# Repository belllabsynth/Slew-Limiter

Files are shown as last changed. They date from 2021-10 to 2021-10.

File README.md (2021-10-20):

# Slew Limiter

This is a simple eurorack slew limiter, with a very low parts count that is quick and easy to build. There are no extra frills, just a pot for slew amount, a toggle switch to select between slewing up, down, or both, one input, and one output. 

I drew the schematic from a stripboard layout done by user Mcshafty on the Look Mum No Computer discourse forums ([link here](https://lookmumnocomputer.discourse.group/t/slew-generator-stripboard-confirmed-working/1865)), which is based off of schematics from [Dintree](https://dintree.com) and [YuSynth](https://yusynth.com).

*General Notes:* 

* Current revision (v1.2) of board is untested as of yet, though past versions have worked as expected. I will update and remove this text when I get my new boards in.
* The included Gerber files have been generated for JLCPCB and have not been tested with manufacturers. I have included silkscreen text on the back of both the main board and the panel to avoid JLC printing the batch number on the front. Remove the text saying "JLCJLCJLCJLC" if printing elsewhere and you care to have that removed.
* JLCPCB does not detect the pcb size for the front panel. You can enter it as 128x20mm.
* Depending on your rack, the v1.0 and v1.1 boards may have been too long and not clear your rails. There are no traces below the output jacks ground leg and you can carefully cut a little bit off the board below there if needed. This have been fixed in v1.2.

*Changes In v1.2:*

* Change C4 and C5 from polarized 10uf capacitors to one (now C3) bipolar 4.7uf capacitor
* Resize main board PCB to 100mm height to fix potential clearance issue and reduce manufacturing cost
* Re-design board to make the build a little bit easier
* Change power header footprint to a shrouded header, taken from the [Winterbloom GitHub](https://github.com/wntrblm)
* Increase silkscreen text size and edgecut line thickness to avoid possible issues at certain PCB houses
* Add "JLCJLCJLCJLC" text to main board PCB and front panel so JLC doesn't put their batch number on the front
* Misc schematic changes to improve readability

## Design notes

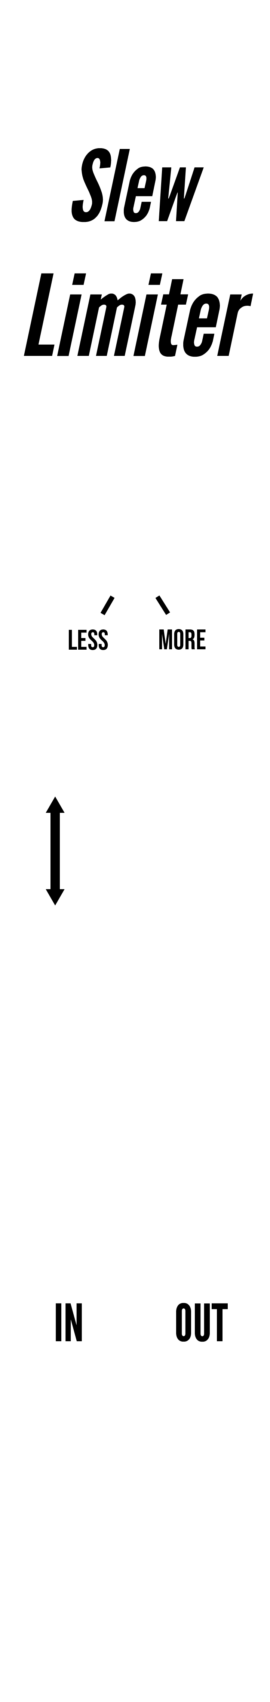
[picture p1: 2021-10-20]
04 Graphics Files/Slew Limiter Panel Graphics.png

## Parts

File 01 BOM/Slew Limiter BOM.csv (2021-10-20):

Reference(s) | Value | Qty | Description
C1, C2 | 10uf | 2 | Polarized radial capacitor
C3 | 4.7uf | 1 | Bipolar radial capacitor
C4, C5 | 100nf | 2 | Ceramic disc capacitor
D1, D2 | 1N5817 | 2 | Diode
D3, D4 | 1N4148 | 2 | Diode
J1 | Input | 1 | Thonkiconn
J2 | Output | 1 | Thonkiconn
JP1 | PWR | 1 | Power header
R1, R2 | 100r | 2 | 1/4w resistor
R3, R4 | 100k | 2 | 1/4w resistor
R5 | 1k | 1 | 1/4w resistor
RV1 | 250k lin | 1 | Alpha 9mm vertical pot
SW1 | ON-OFF-ON | 1 | SPDT switch – Tayda 1M series
U1 | TL072 | 1 | OpAmp

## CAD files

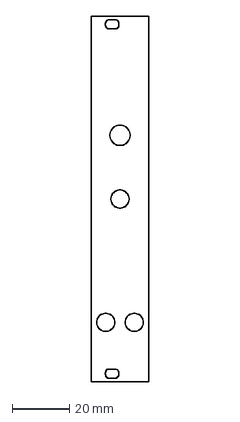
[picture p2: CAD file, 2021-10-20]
04 Graphics Files/Slew Limiter Panel Edge Cuts.dxf
20.0 x 128.0 mm

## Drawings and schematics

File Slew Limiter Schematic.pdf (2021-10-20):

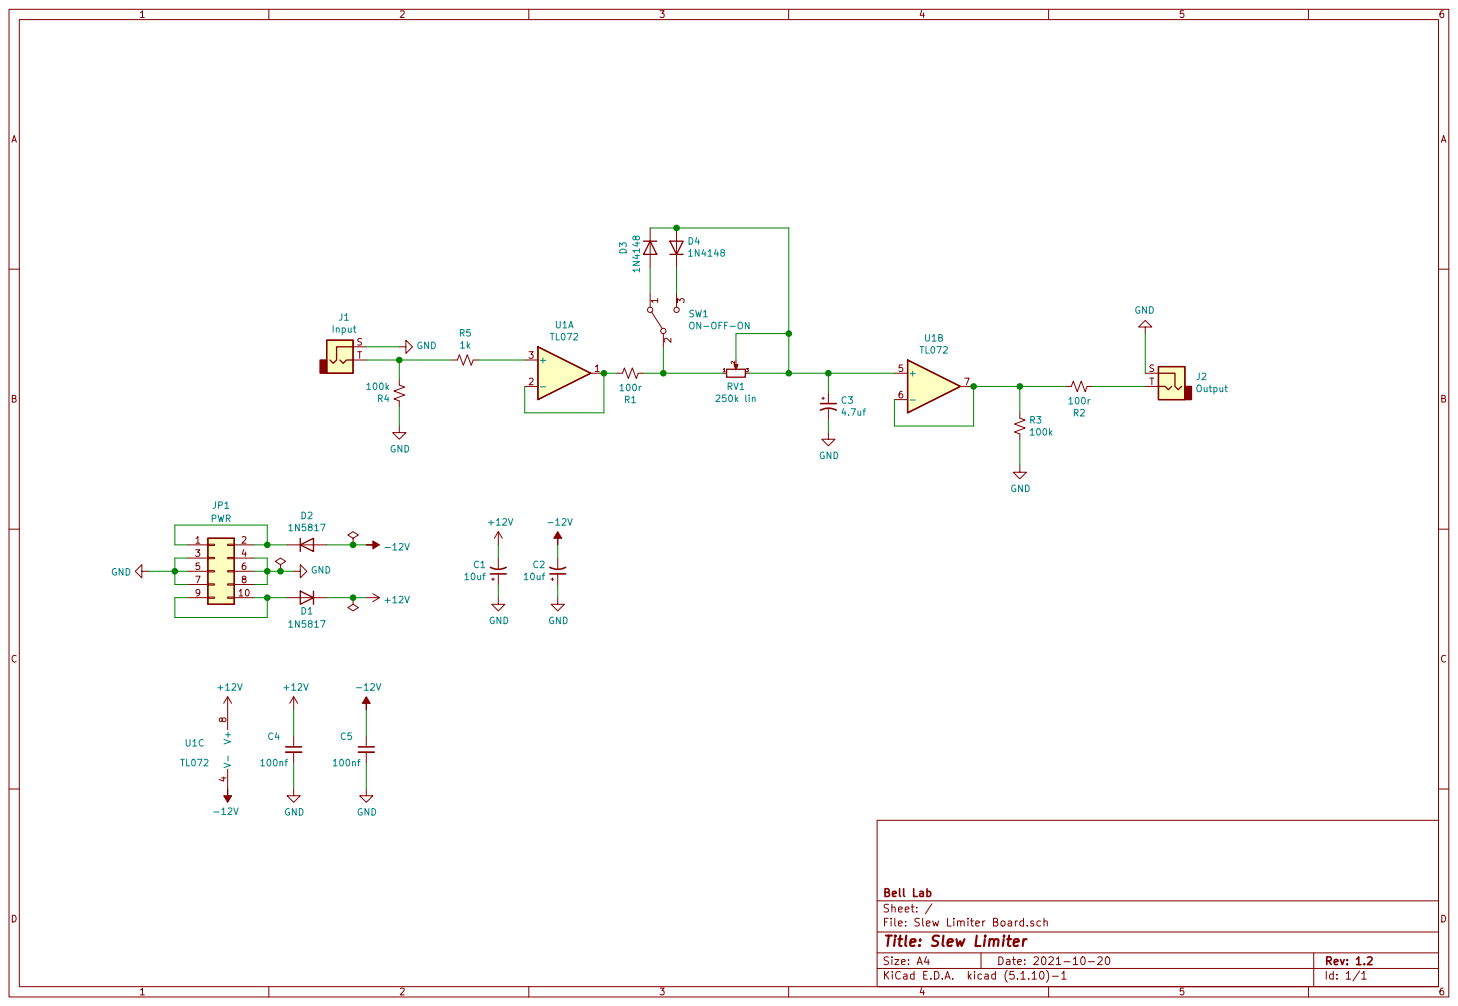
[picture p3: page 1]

3 SW1 ON-OFF-ON D3 1N4148 GND

Id: 1/1 Title: Slew Limiter File: Slew Limiter Board.sch Sheet: / Bell Lab D2

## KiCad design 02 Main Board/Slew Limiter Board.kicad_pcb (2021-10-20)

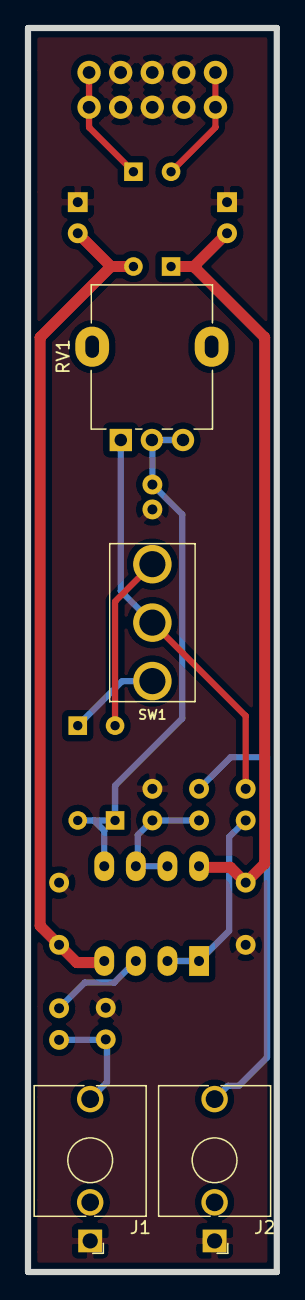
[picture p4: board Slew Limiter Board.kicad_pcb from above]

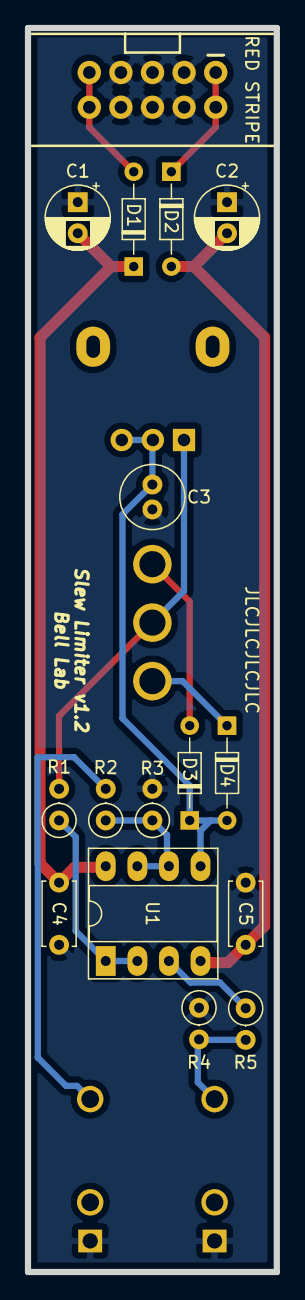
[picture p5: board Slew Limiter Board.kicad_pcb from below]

Board: 2 copper layers, 20.0 x 100.0 mm, 20 parts (16 on the bottom side), 14 nets.

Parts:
C1, C2: 10uf; CP_Radial_D5.0mm_P2.50mm
C3: 4.7uf; C_Radial_D5.0mm_H11.0mm_P2.00mm
C4, C5: 100nf; C_Disc_D5.0mm_W2.5mm_P5.00mm
D1, D2: 1N5817; D_DO-34_SOD68_P7.62mm_Horizontal
D3, D4: 1N4148; D_DO-34_SOD68_P7.62mm_Horizontal
J1: Input; Jack_3.5mm_QingPu_WQP-PJ398SM_Vertical_CircularHoles
J2: Output; Jack_3.5mm_QingPu_WQP-PJ398SM_Vertical_CircularHoles
JP1: PWR; Eurorack_Power
R1, R2: 100r; R_Axial_DIN0207_L6.3mm_D2.5mm_P2.54mm_Vertical
R3, R4: 100k; R_Axial_DIN0207_L6.3mm_D2.5mm_P2.54mm_Vertical
R5: 1k; R_Axial_DIN0207_L6.3mm_D2.5mm_P2.54mm_Vertical
RV1: 250k lin; Potentiometer_Alpha_RD901F-40-00D_Single_Vertical
SW1: ON-OFF-ON; SPDT-toggle-switch-1M-series
U1: TL072; DIP-8_W7.62mm_Socket_LongPads

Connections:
+12V: C1.2, C4.1, D1.1, U1.8
-12V: C2.2, C5.1, D2.2, U1.4
GND: C1.1, C2.1, C3.2, C4.2, C5.2, J1.S, J2.S, JP1.3, JP1.4, JP1.5, JP1.6, JP1.7, JP1.8, R3.2, R4.1
unnamed: C3.1, D3.1, D4.2, RV1.2, RV1.3, U1.5
unnamed: D1.2, JP1.9, JP1.10
unnamed: D2.1, JP1.1, JP1.2
unnamed: D3.2, SW1.1
unnamed: D4.1, SW1.3
unnamed: J1.T, R4.2, R5.2
unnamed: J2.T, R2.2
unnamed: R1.1, U1.1, U1.2
unnamed: R1.2, RV1.1, SW1.2
unnamed: R2.1, R3.1, U1.6, U1.7
unnamed: R5.1, U1.3

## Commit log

2021-10-10 misc changes see description
    Slightly shrink board (no moving of components)
    Increase silkscreen text size
    Increase edge cuts line thickness
    [Slew Limiter Board-B_Cu.gbl, Slew Limiter Board-B_Mask.gbs, Slew Limiter Board-B_Paste.gbp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]
2021-10-20 Update to v1.2
    Many changes, see readme for list
    [Slew Limiter BOM.csv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]
2021-10-20 Front panel text fix
    Nudge input and output text
    [Slew Limiter Board.sch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]
